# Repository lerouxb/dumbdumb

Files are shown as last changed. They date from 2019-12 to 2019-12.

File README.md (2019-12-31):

DumbDumb Terminal
===

A little smart hardware serial terminal for use with REPLs like MicroPython in the form of a Feather Wing.

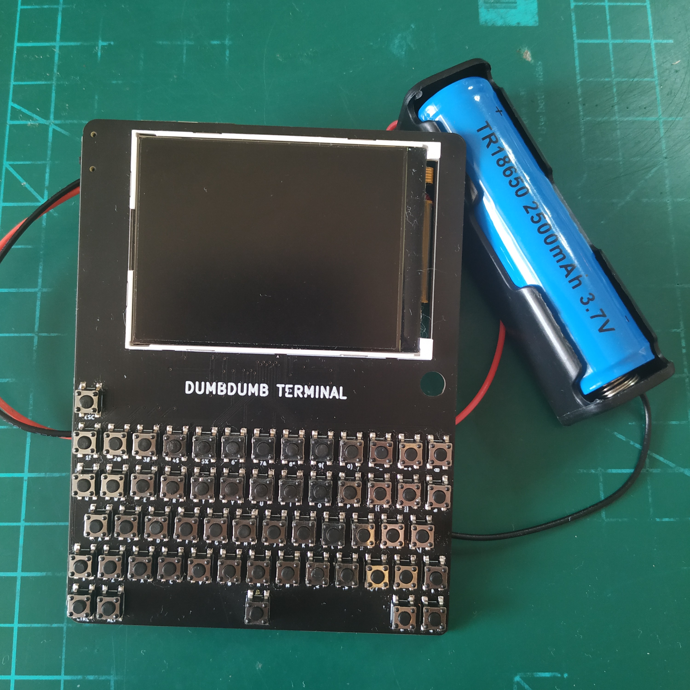
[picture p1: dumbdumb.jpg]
dumbdumb


For more info, see the [Hackaday.io project page](https://hackaday.io/project/168722-dumbdumb).

Directory structure
---

### cpp

platform.io and arduino stm32-core based firmware for the stm32g071r8. Scans the keyboard matrix, handles the LCD. Reads and writes over serial. Understands a small subset of VT100 terminal functionality. Just enough to fully support MicroPython's readline REPL.

### node

Some node.js based code to parse, modify and format KiCAD's PCB file format which is some variant of LISP. Contains a script that uses all of that to modify a pcb file to layout the keyboard's buttons. A lot more convenient for making changes to the button positioning than moving each of them around manually in KiCAD's interface every time I want to make changes to the layout.

### pcb

KiCAD files for the PCB. Includes tons of custom symbols and parts.

### py

The dupterm code for the esp32 port of MicroPython to duplicate the REPL on UART 2 which is the one that's exposed by the Adafruit Huzzah32 Feather's RX and TX pins. ie. the ones that are connected to DumbDumb's STM32 microcontroller when you plug the Feather in.

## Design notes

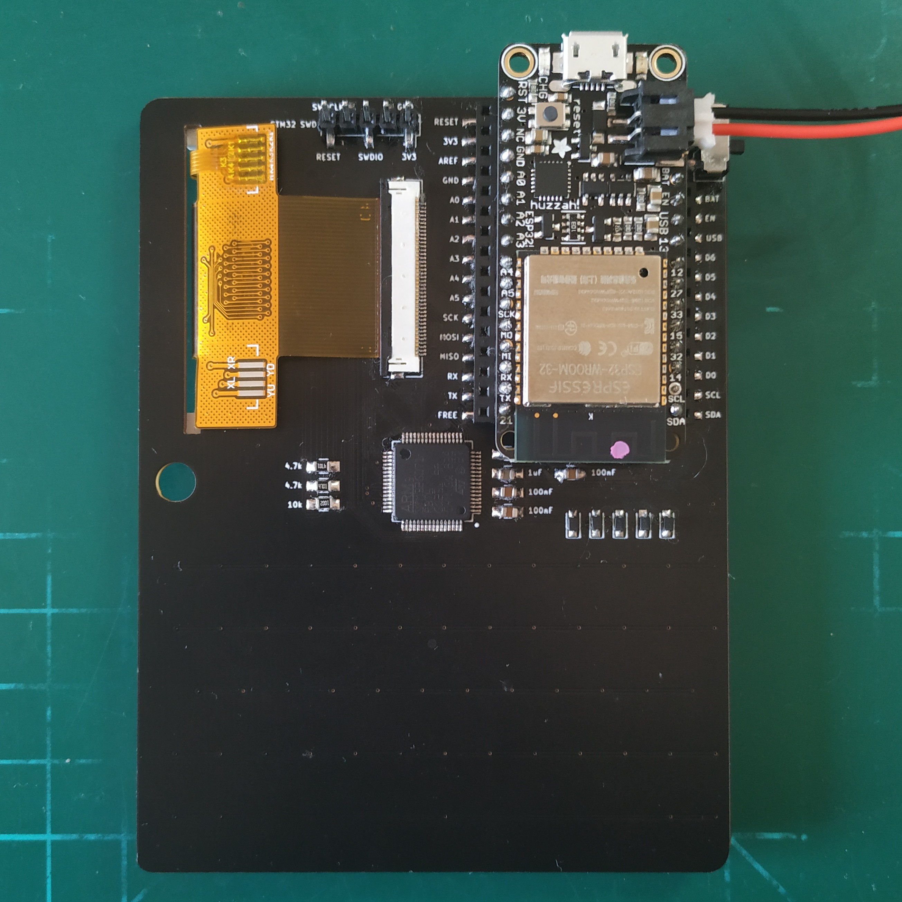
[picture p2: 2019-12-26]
dumbdumb-backside.jpg

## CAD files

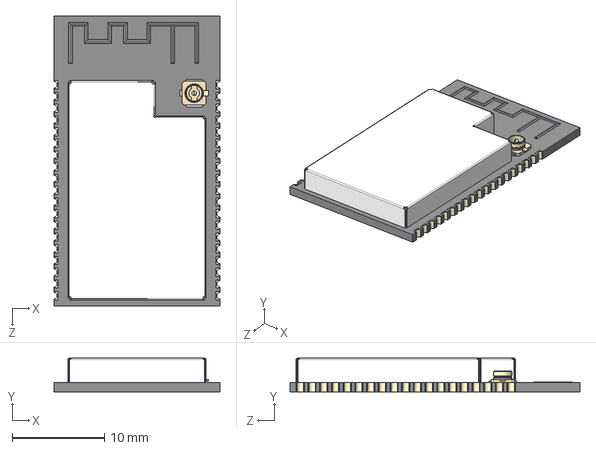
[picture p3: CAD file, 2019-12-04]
pcb/ESP32-WROVER-I--3DModel-STEP-56544.STEP
18.0 x 3.65 x 31.4 mm

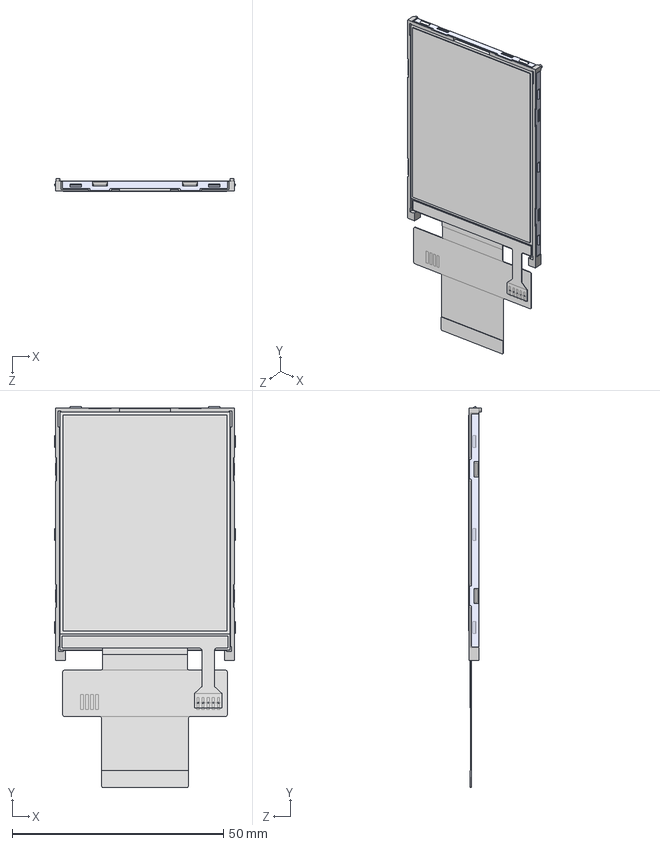
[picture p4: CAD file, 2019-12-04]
pcb/NHD-2.4-240320CF-Cxxx.step
42.9 x 90.2 x 3.17 mm
bezel 2
V.A
Cable
Cable 2
frame
lens

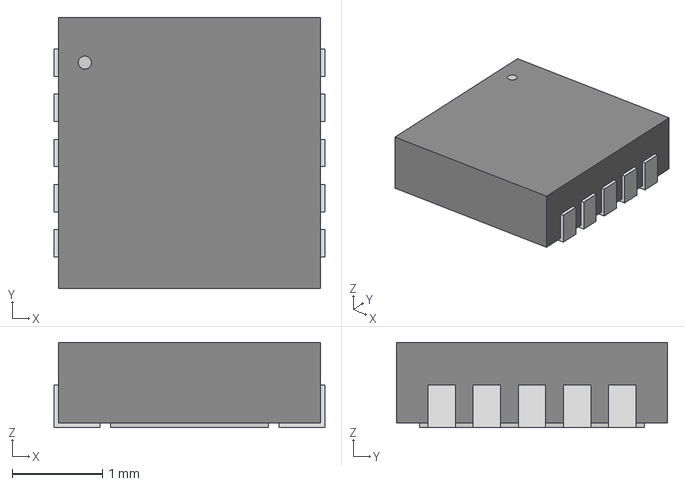
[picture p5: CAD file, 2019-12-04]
pcb/DFN10_3x3MC.step
3.00 x 3.00 x 0.942 mm

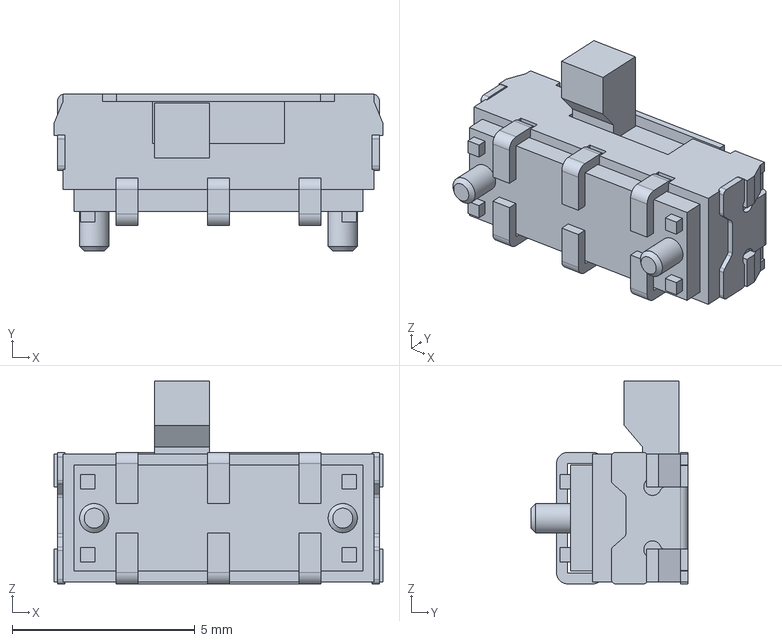
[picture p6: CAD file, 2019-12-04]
pcb/JS202011JAQN.stp
9.00 x 4.30 x 5.55 mm

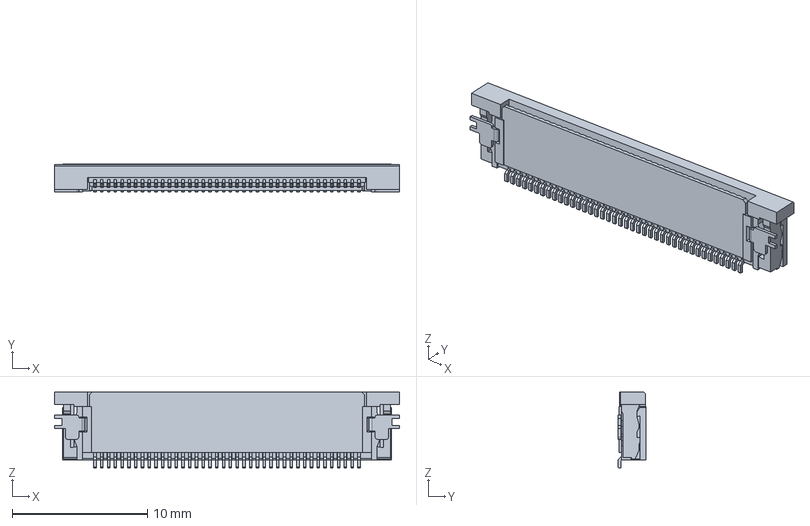
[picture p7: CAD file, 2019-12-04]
pcb/541324062.stp
25.5 x 2.05 x 5.60 mm

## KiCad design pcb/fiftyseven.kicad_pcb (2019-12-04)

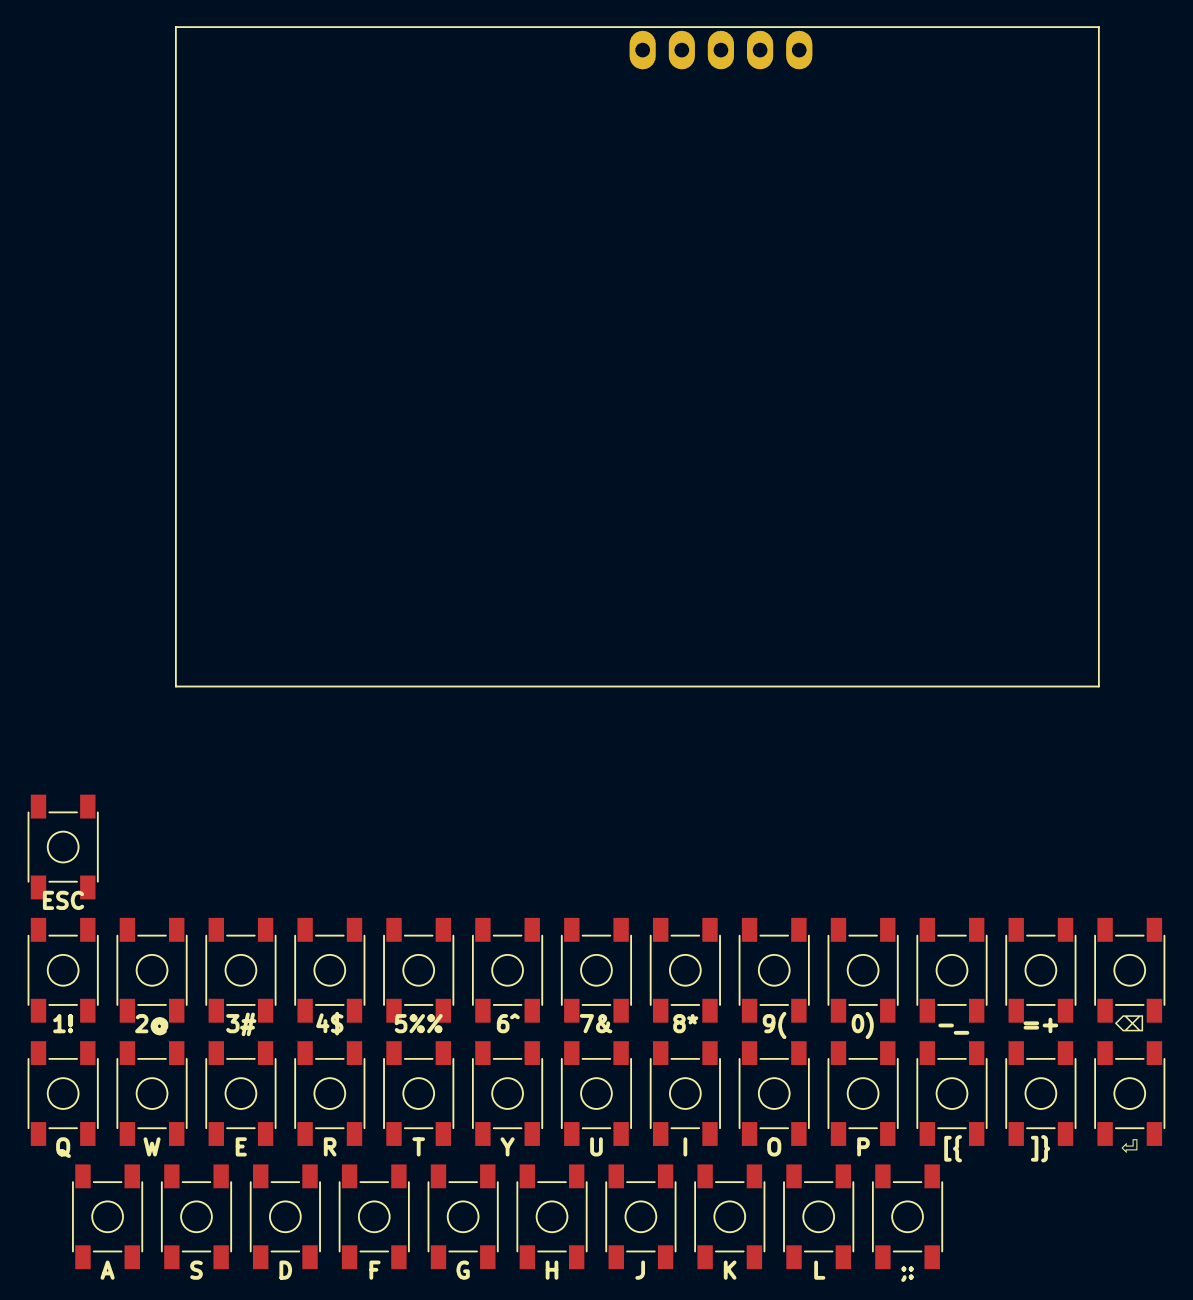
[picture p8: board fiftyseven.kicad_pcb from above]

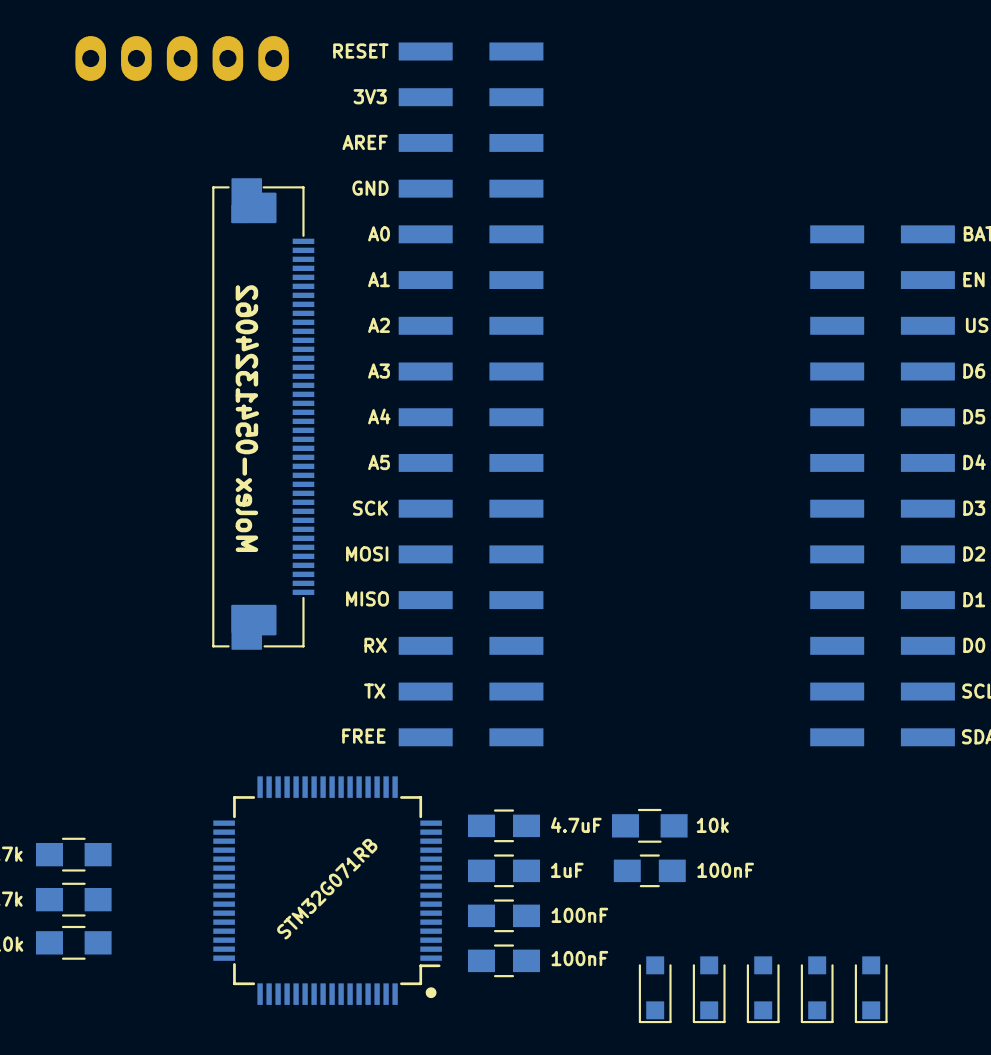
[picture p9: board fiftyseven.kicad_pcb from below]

Board: 2 copper layers, 56 parts (17 on the bottom side), 53 nets, no tracks yet.

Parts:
C10, C12, C17: 100nF; C_0805_HandSoldering
C11: 4.7uF; C_0805_HandSoldering
C13: 1uF; C_0805_HandSoldering
D1, D2, D3, D4, D5: D; D_SOD-323_HandSoldering
J1: Feather; FeatherHolderSMD
J2: STM32 SWD; SWD_Header
R1, R12: 10k; R_0805_HandSoldering
R10, R11: 4.7k; R_0805_HandSoldering
SW0:0, SW0:1, SW0:2, SW0:3, SW0:4, SW0:5, SW0:6, SW0:7, SW0:8, SW0:9, SW0:10, SW0:11, SW0:12, SW1:0, SW1:1, SW1:2, SW1:3, SW1:4, SW1:5, SW1:6, SW1:7, SW1:8, SW1:9, SW1:10, SW1:11, SW1:12, SW2:0, SW2:1, SW2:2, SW2:3, SW2:4, SW2:5, SW2:6, SW2:7, SW2:8, SW2:9, SW2:10: SW_Push; 4.5mm-switch
SW:ESC1: SW_Push; 4.5mm-switch
U1: STM32G071RB; STM32G0-LQFP-64
U6: 240x320_16bit; LCD-320x240

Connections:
+3V3: C10.1, C11.1, C12.1, C13.1, J1.14, J2.1, R1.1, R10.1, R11.1, SW:ESC1.1, U1.6, U1.7, U1.8
C0: SW0:0.2, SW1:0.2, SW2:0.2, U1.11
C1: SW0:1.2, SW1:1.2, SW2:1.2, U1.13
C2: SW0:2.2, SW1:2.2, SW2:2.2, U1.14
C3: SW0:3.2, SW1:3.2, SW2:3.2, U1.15
C4: SW0:4.2, SW1:4.2, SW2:4.2, U1.16
C5: SW0:5.2, SW1:5.2, SW2:5.2, U1.17
C6: SW0:6.2, SW1:6.2, SW2:6.2, U1.18
C7: SW0:7.2, SW1:7.2, SW2:7.2, U1.19
C8: SW0:8.2, SW1:8.2, SW2:8.2, U1.20
C9: SW0:9.2, SW1:9.2, SW2:9.2, U1.21
C10: SW0:10.2, SW1:10.2, U1.22
C11: SW0:11.2, SW1:11.2, U1.23
C12: SW0:12.2, SW1:12.2, U1.24
DB0: U1.27, U6.14
DB1: U1.28, U6.15
DB2: U1.29, U6.16
DB3: U1.57, U6.17
DB4: U1.58, U6.18
DB5: U1.59, U6.19
DB6: U1.60, U6.20
DB7: U1.61, U6.21
DB8: U1.62, U6.22
DB9: U1.63, U6.23
DB10: U1.30, U6.24
DB11: U1.31, U6.25
DB12: U1.32, U6.26
DB13: U1.33, U6.27
DB14: U1.34, U6.28
DB15: U1.35, U6.29
DC: U1.48, U6.11
ESC: SW:ESC1.2, U1.10
GND: C10.2, C11.2, C12.2, C13.2, C17.2, J1.16, J2.2, R12.1, U1.9, U6.1, U6.10, U6.33, U6.34, U6.35, U6.36, U6.37, U6.39
IM0: U1.36, U6.31
unnamed: D1.1, SW0:0.1, SW0:1.1, SW0:2.1, SW0:3.1, SW0:4.1, SW0:5.1, SW0:6.1, SW0:7.1, SW0:8.1, SW0:9.1, SW0:10.1, SW0:11.1, SW0:12.1
unnamed: D2.1, SW1:0.1, SW1:1.1, SW1:2.1, SW1:3.1, SW1:4.1, SW1:5.1, SW1:6.1, SW1:7.1, SW1:8.1, SW1:9.1, SW1:10.1, SW1:11.1, SW1:12.1
unnamed: D3.1, SW2:0.1, SW2:1.1, SW2:2.1, SW2:3.1, SW2:4.1, SW2:5.1, SW2:6.1, SW2:7.1, SW2:8.1, SW2:9.1
unnamed: U6.7, U6.8
R0: D1.2, U1.1
R1: D2.2, U1.2
R2: D3.2, U1.3
R3: D4.2, U1.4
R4: D5.2, U1.5
RESET: C17.1, J1.13, J2.5, R1.2, U1.12
RX: J1.26, U1.25
SCL: J1.2, R10.2, U1.37
SDA: J1.1, R11.2, U1.42
SWDCLK: J2.4, R12.2, U1.46
SWDIO: J2.3, U1.45
TX: J1.27, U1.26
~RD: U1.39, U6.13
~RES: U1.38, U6.30
~WR: U1.47, U6.12

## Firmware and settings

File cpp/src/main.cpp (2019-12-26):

#include <Arduino.h>
#include <st7789vi.h>
#include <keyboard.h>
#include <pixel_buffer.h>
#include <text_buffer.h>
#include <color_utils.h>

TextBuffer tb;

HardwareSerial Serial1(PC5, PC4);

int FG_COLOR;

void setup() {
    //FG_COLOR = rgb_to_12bit(1, 0.75, 0);
    FG_COLOR = 4095; // white

    tb_init(&tb);
    tft_init();
    keyboard_init();

    Serial1.begin(115200);

    // hack so you get a prompt even if the target was up before the terminal
    Serial1.write("\r");
}

void loop() {

    int i;
    int length;
    int row;
    int col;
    char line[TEXTBUFFER_LENGTH + 1];
    int line_length;
    int num_bytes;
    int num_lines;
    unsigned char c;

    // prioritise reading the serial buffer above all else
    length = Serial1.available();
    if (length > 0) {
        while (length > 0) {
            num_bytes = Serial1.readBytes(line, length);
            line[num_bytes] = 0;
            tb_write(&tb, line);
            length = Serial1.available();
        }
    }
    else {
        if (tb_error != NULL) {
            Serial1.write(tb_error);
            tb_error = NULL;
        }

        keyboard_poll();
        keyboard_to_vt100();

        length = strlen(key_buffer);
        if (length) {
            Serial1.write(key_buffer);
        }

        num_lines = tb_num_lines(&tb);

        for (row=0; row<ROWS; row++) {
            if (!tb.dirty[row]) {
                continue;
            }
            tb.dirty[row] = false;

            pixel_buffer_clear();

            line[0] = 0;
            if (row < num_lines) {
                tb_get_screen_line(&tb, line, row);
            }
            line_length = strlen(line);

            for (col=0; col<line_length; col++) {
                c = (unsigned char) line[col];
                if (c == 0) {
                    break;
                }
                pixel_buffer_draw_char(col*6, 0, c, FG_COLOR, 0);
            }

            // draw the cursor if it is on this row
            if (row == tb_y(&tb)) {
                pixel_buffer_draw_cursor(tb_x(&tb)*6, 0, FG_COLOR);
            }

            tft_copy_pixel_buffer(row);
        }
    }
}

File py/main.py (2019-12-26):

from machine import Timer, UART
import micropython

uart = UART(2, 115200)
uart.init(115200, bits=8, parity=None, stop=1)
uos.dupterm(uart)

timer = Timer(-1)

def schedule_poll(ignore=None):
    micropython.schedule(check, 0)

def check(ignore=None):
    if uart.any():
        uos.dupterm_notify(uart)
    timer.init(period=10, mode=Timer.ONE_SHOT, callback=schedule_poll)

check()

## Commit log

2019-12-04 move over pcb files from fiftyseven
    [541324062.stp, DFN10_3x3MC.step, ESP32-WROVER-I--3DModel-STEP-56544.STEP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]
2019-12-26 node lib & script(s) for parsing, modifying and formatting kicad pcb lisp files
